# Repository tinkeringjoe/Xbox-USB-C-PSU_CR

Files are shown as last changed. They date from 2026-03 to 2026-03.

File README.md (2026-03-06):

This fork is for the following:

1) Reducing cost by using a cheap single IC that requires barely any supporting passives for USB-PD negotiating.
2) Updating power good signal to be an AND of the 4 power rails rather than a wired OR for power good.
3) Move components from back to front to simplify manufacturing.
4) Change from solder pads to through holes for power cabling; add enough holes for all XBOX revisions cabling.

Goals 1-4 completed. Additionally changed the following.
Inductor/output capacitors for all power rails have been updated per datasheet equations to minimize ripple.
Cost reduced components (BOM will remain hidden until testing is completed.)

This board supports the following power on the rails with an expected ripple of around 1%
5V - 15A
12V - 1.5A
3.3V - 5A
3.3VSB - 700mA

5 turn-key boards have been ordered to test. The following testing is to occur before even touching an XBOX.

1.) Power supply ripple is to be measured under the following conditions (1%, 25%, 50%, 100% of peak load). Should not exeed 5%.
2.) Load removal testing; 100% to 0% load. Should not exceed 10% of voltage rail.

Once these requirements have been satisfied real-hardware testing can occur.

# Xbox-USB-C-PSU
The first ever USB C PSU for the original Xbox

# NOTE:
This board currently supports all 3 Xbox motherboard revisions, but requires a different BOM for 009 and 012 than 121.
If you don't know what revision your Xbox is, you can find out with this guide: [https://www.herringhardware.com/xboxrevisions](https://www.herringhardware.com/XboxRevisions.html)

# REPO STRUCTURE:
All source files for the PCB are contained within the respective folder for each of the 3 official Xbox PCB revions,
-121 to start with, and -009 and -012 will be added soon.
Production files to manufacture the PCBs are located in [Releases](https://github.com/Redherring32/Xbox-USB-C-PSU/releases)

# PCB SPECS:
* 4 layers
* 151.739x39.78mm
* 1oz copper (all layers), heat issues may result from skimping on this
* filled vias (VIPPO) for assembly reasons due to via in pad

kicad_rvZLV58yR5

## LICENSE:
Licensed under
the TAPR Open hardware license (www.tapr.org/OHL)

©Redherring32 2025

## DISCLAIMER:
I offer this with no warranty, express or implied, and I am NOT responsible for anything that may happen as a result of misuse of this PCB.
You have been warned.

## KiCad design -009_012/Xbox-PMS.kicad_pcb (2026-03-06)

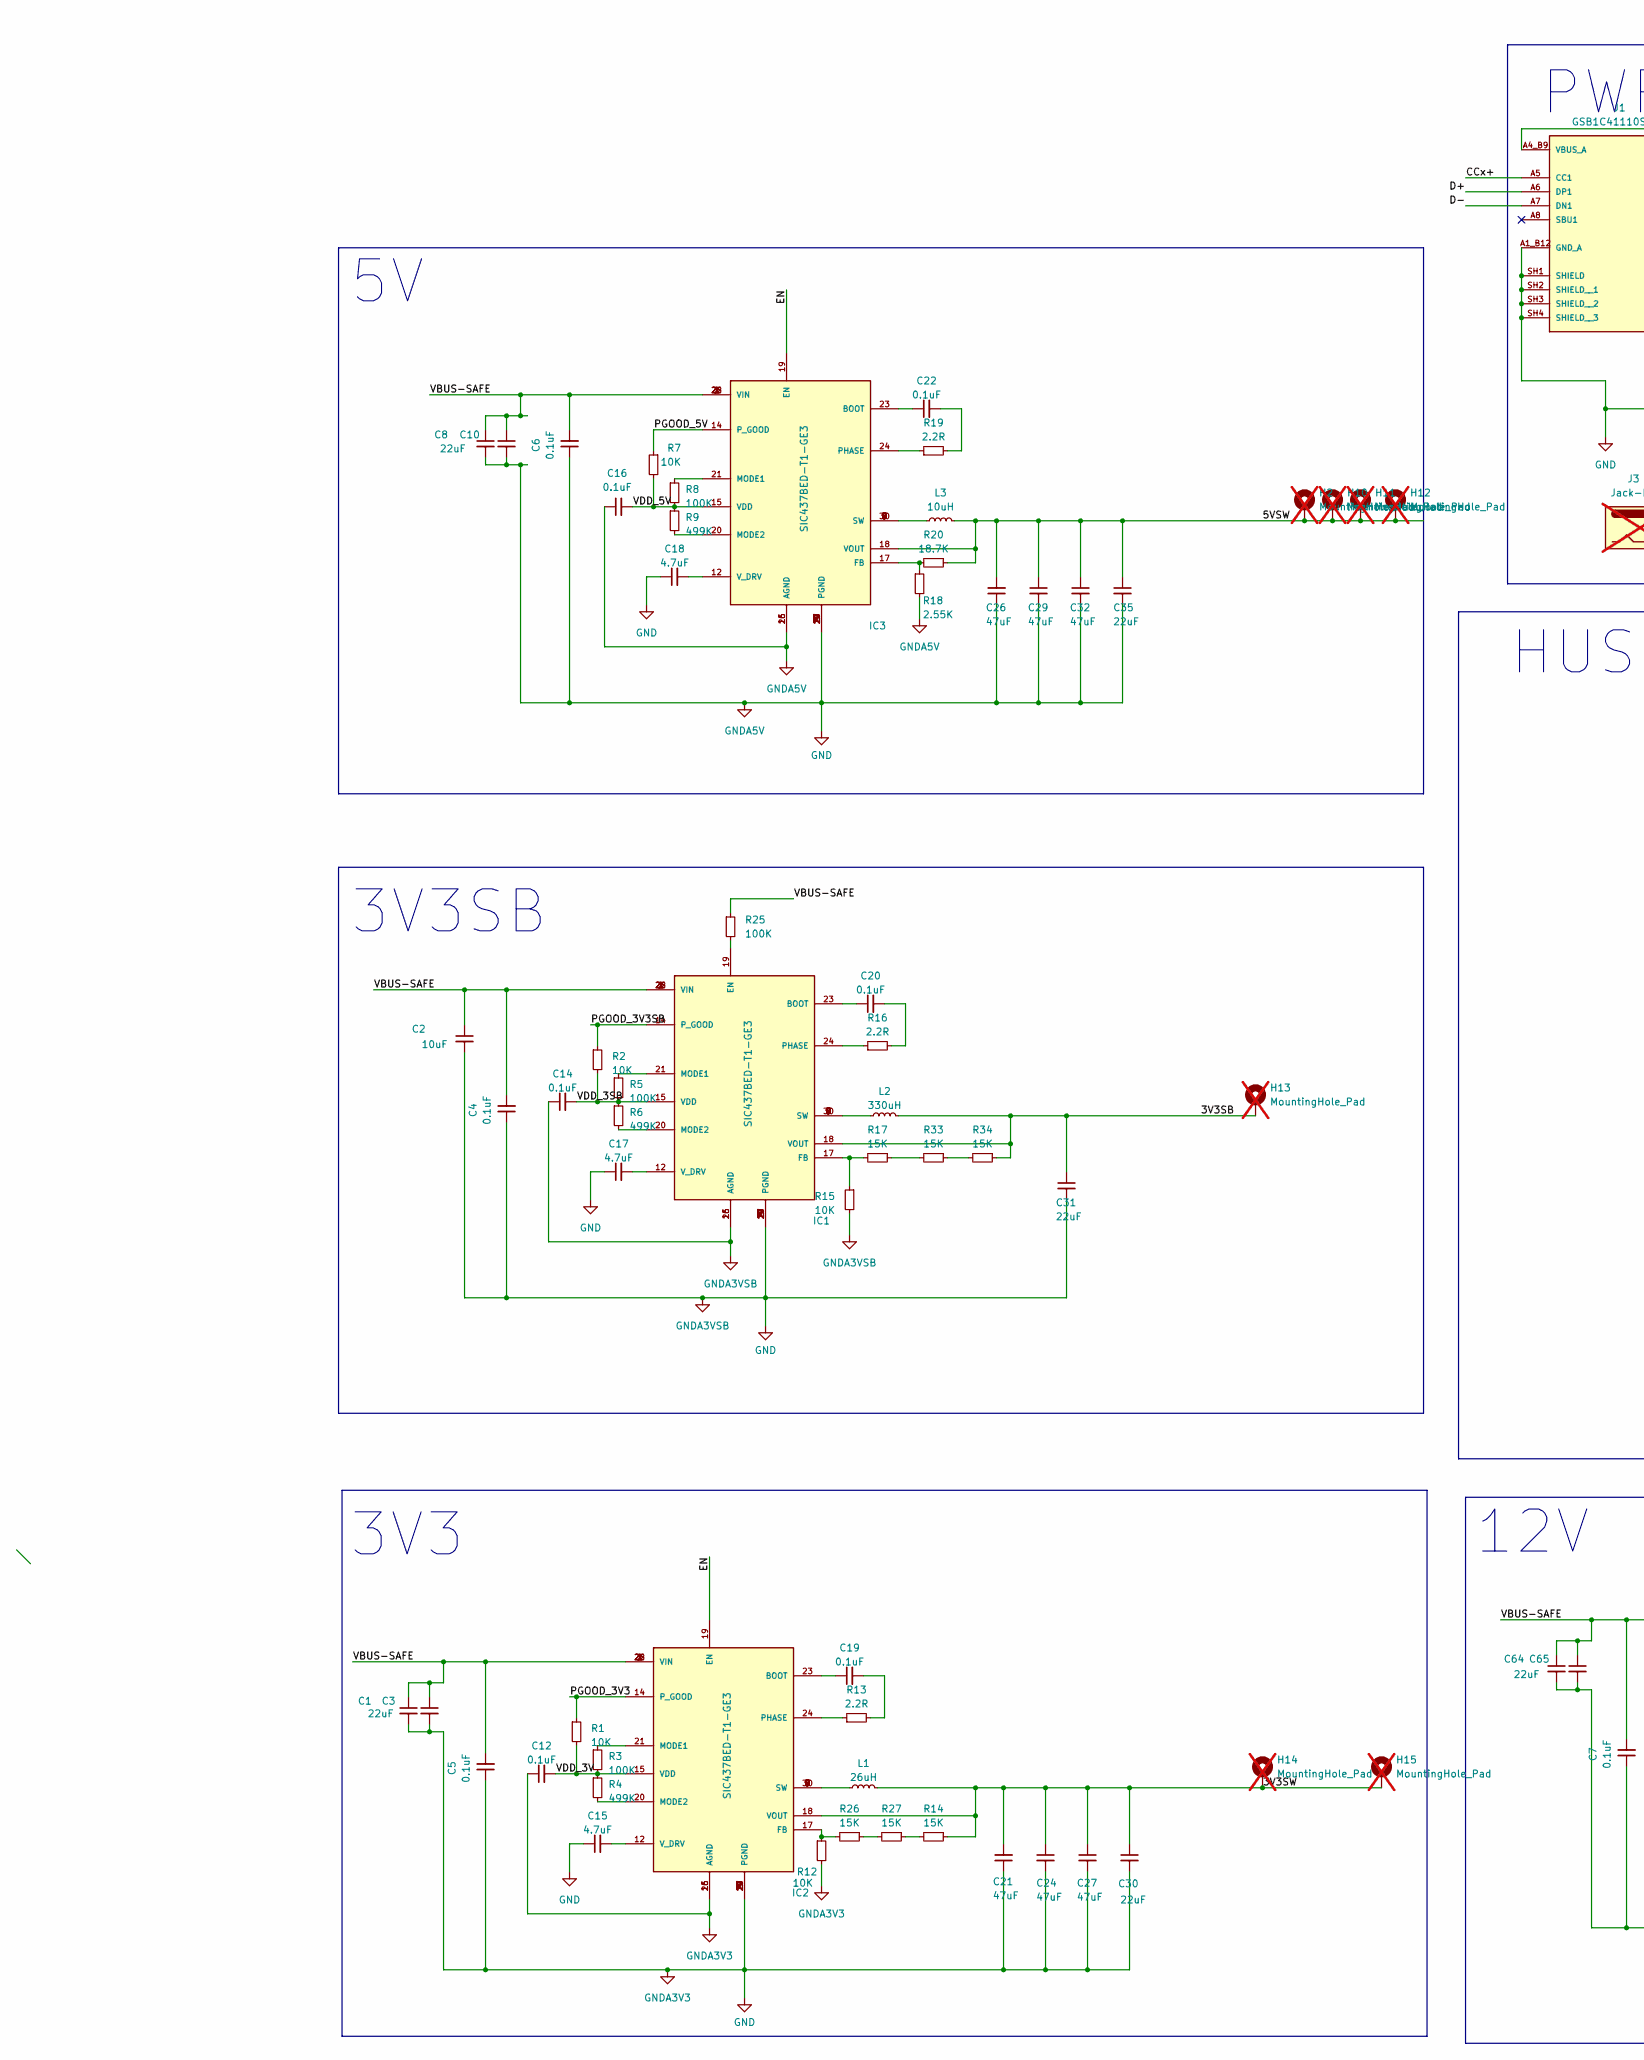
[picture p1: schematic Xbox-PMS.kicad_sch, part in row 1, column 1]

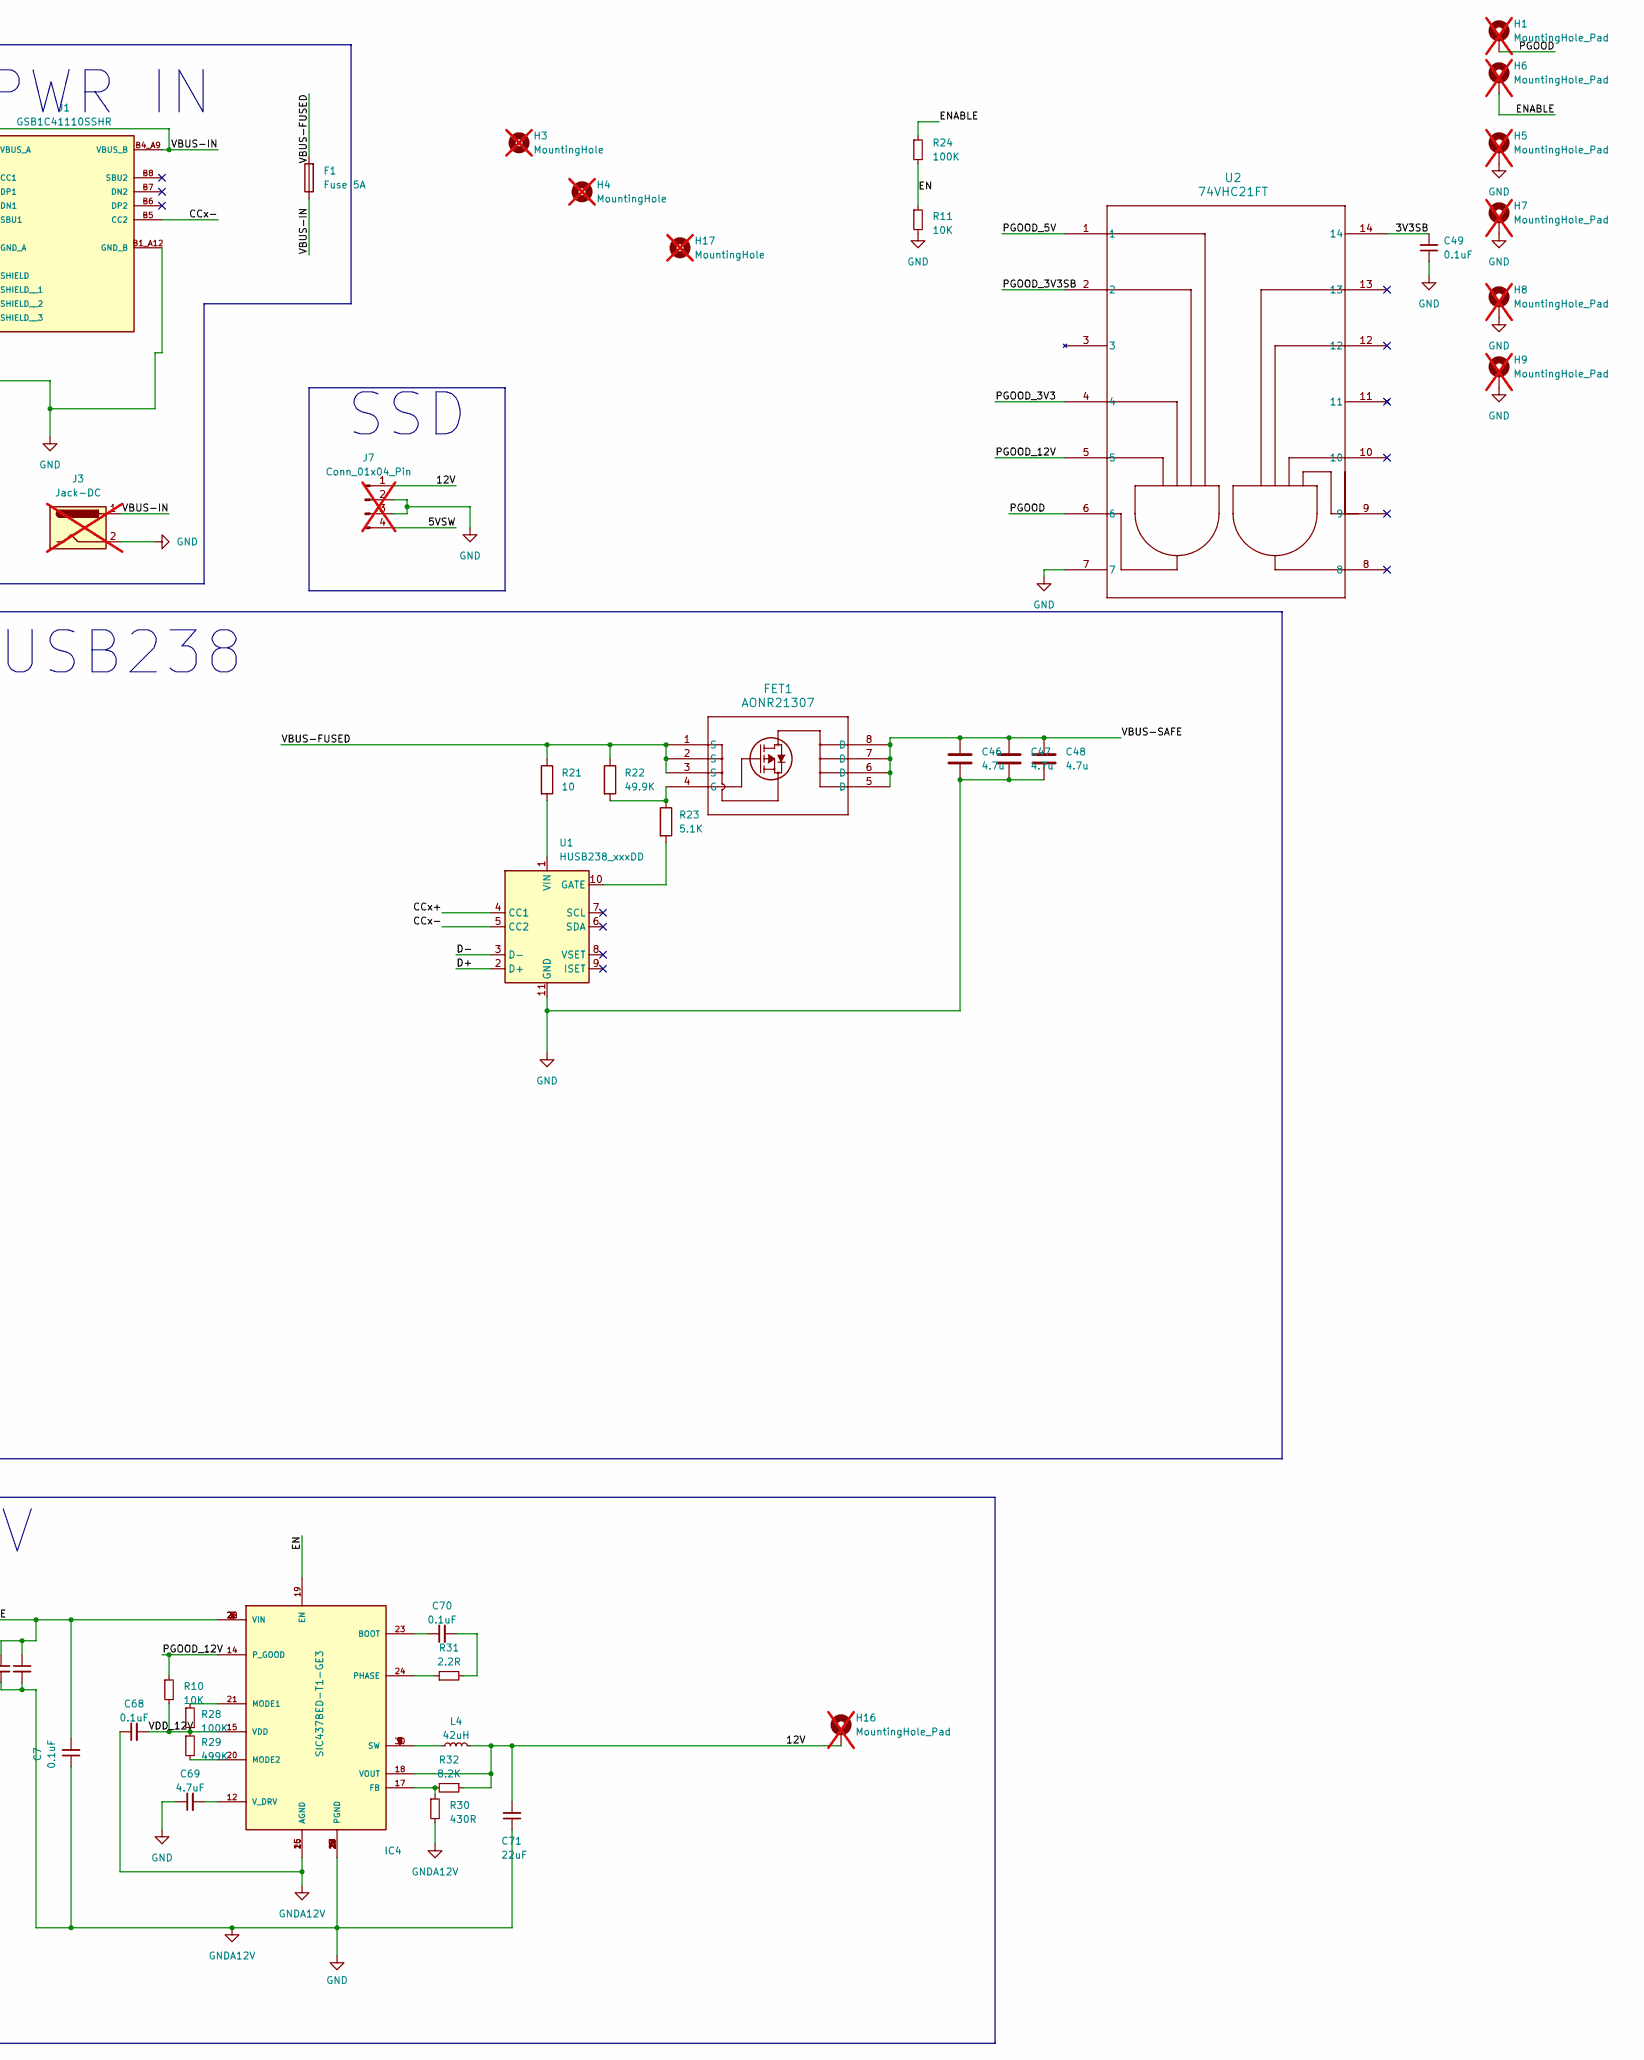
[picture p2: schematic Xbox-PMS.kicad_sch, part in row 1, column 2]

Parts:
C1, C3, C8, C10, C64, C65: 22uF; C_1210_3225Metric
C2: 10uF; C_1210_3225Metric
C4, C5, C6, C7, C12, C14, C16, C19, C20, C22, C49, C68, C70: 0.1uF; C_0402_1005Metric
C15, C17, C18, C69: 4.7uF; C_0603_1608Metric
C21, C24, C26, C27, C29, C32: 47uF; C_1210_3225Metric
C30, C31, C35: 22uF; C_0603_1608Metric
C46, C47, C48: 4.7u; C_1210_3225Metric
C71: 22uF; R_0805_2012Metric
F1: Fuse 5A; Fuse_2512_6332Metric
FET1: AONR21307; DFN8_3x3_EP_AOS
H1, H2, H5, H6, H7, H8, H9, H10, H11, H12, H13, H14, H15, H16: MountingHole_Pad; TestPoint_THTPad_2.5x2.5mm_Drill1.2mm; not fitted
H3, H4, H17: MountingHole; MountingHole_2.2mm_M2; not fitted
IC1, IC2, IC3, IC4: SIC437BED-T1-GE3; SIC437BEDT1GE3
J1: GSB1C41110SSHR; AMPHENOL_GSB1C41110SSHR; PARTREV AX1
J3: Jack-DC; BarrelJack_CUI_PJ-063AH_Horizontal; not fitted
J7: Conn_01x04_Pin; FDD Connector; not fitted
L1: 26uH; fch1350-270M
L2: 330uH; IND_SRN8040TA-331M
L3: 10uH; MDA1870-100M
L4: 42uH; IND_ETQ-P4M470KFM_PAN
R1, R2, R7, R10, R11, R12, R15: 10K; R_0402_1005Metric
R3, R5, R8, R24, R25, R28: 100K; R_0402_1005Metric
R4, R6, R9, R29: 499K; R_0402_1005Metric
R13, R16, R19, R31: 2.2R; R_0402_1005Metric
R14, R17, R26, R27, R33, R34: 15K; R_0402_1005Metric
R18: 2.55K; R_0402_1005Metric
R20: 18.7K; R_0402_1005Metric
R21: 10; R_0402_1005Metric
R22: 49.9K; R_0402_1005Metric
R23: 5.1K; R_0402_1005Metric
R30: 430R; R_0402_1005Metric
R32: 8.2K; R_0402_1005Metric
U1: HUSB238_xxxDD; WDFN-10-1EP_3x3mm_P0.5mm_EP1.8x2.5mm
U2: 74VHC21FT; TSSOP14B_TOS

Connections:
/3V3SB: C31.1, C49.2, H13.1, IC1.18 (VOUT), L2.2, R34.1, U2.14
/3V3SW: C21.2, C24.1, C27.1, C30.1, H14.1, H15.1, IC2.18 (VOUT), L1.2, R14.1
/5VSW: C26.2, C29.1, C32.1, C35.1, H2.1, H10.1, H11.1, H12.1, IC3.18 (VOUT), J7.4, L3.2, R20.1
/12V: C71.2, H16.1, IC4.18 (VOUT), J7.1, L4.2, R32.1
/CCx+: J1.A5 (CC1), U1.4 (CC1)
/CCx-: J1.B5 (CC2), U1.5 (CC2)
/D+: J1.A6 (DP1), U1.2 (D+)
/D-: J1.A7 (DN1), U1.3 (D-)
/EN: IC2.19 (EN), IC3.19 (EN), IC4.19 (EN), R11.1, R24.2
/ENABLE: H6.1, R24.1
/PGOOD: H1.1, U2.6
/PGOOD_3V3: IC2.14 (P_GOOD), R1.1, U2.4
/PGOOD_3V3SB: IC1.14 (P_GOOD), R2.1, U2.2
/PGOOD_5V: IC3.14 (P_GOOD), R7.1, U2.1
/PGOOD_12V: IC4.14 (P_GOOD), R10.1, U2.5
/VBUS-FUSED: F1.2, FET1.1 (S), FET1.2 (S), FET1.3 (S), R21.1, R22.1
/VBUS-IN: F1.1, J1.A4_B9 (VBUS_A), J1.B4_A9 (VBUS_B), J3.1
/VBUS-SAFE: C1.1, C2.1, C3.1, C4.2, C5.2, C6.2, C7.2, C8.1, C10.1, C46.1, C47.1, C48.1, C64.1, C65.1, FET1.5 (D), FET1.6 (D), FET1.7 (D), FET1.8 (D), IC1.1 (VIN), IC1.2 (VIN), IC1.22 (VIN), IC1.26 (VIN), IC2.1 (VIN), IC2.2 (VIN), IC2.22 (VIN), IC2.26 (VIN), IC3.1 (VIN), IC3.2 (VIN), IC3.22 (VIN), IC3.26 (VIN), IC4.1 (VIN), IC4.2 (VIN), IC4.22 (VIN), IC4.26 (VIN), R25.1
/VDD_3SB: C14.2, IC1.15 (VDD), R2.2, R5.2, R6.1
/VDD_3V: C12.2, IC2.15 (VDD), R1.2, R3.2, R4.1
/VDD_5V: C16.2, IC3.15 (VDD), R7.2, R8.2, R9.1
/VDD_12V: C68.2, IC4.15 (VDD), R10.2, R28.2, R29.1
GND: C1.2, C2.2, C3.2, C4.1, C5.1, C6.1, C7.1, C8.2, C10.2, C12.1, C14.1, C15.1, C16.1, C17.1, C18.1, C21.1, C24.2, C26.1, C27.2, C29.2, C30.2, C31.2, C32.2, C35.2, C46.2, C47.2, C48.2, C49.1, C64.2, C65.2, C68.1, C69.1, C71.1, H5.1, H7.1, H8.1, H9.1, IC1.3 (PGND), IC1.4 (PGND), IC1.13 (PGND), IC1.16 (AGND), IC1.25 (AGND), IC1.27 (PGND), IC1.29 (PGND), IC2.3 (PGND), IC2.4 (PGND), IC2.13 (PGND), IC2.16 (AGND), IC2.25 (AGND), IC2.27 (PGND), IC2.29 (PGND), IC3.3 (PGND), IC3.4 (PGND), IC3.13 (PGND), IC3.16 (AGND), IC3.25 (AGND), IC3.27 (PGND), IC3.29 (PGND), IC4.3 (PGND), IC4.4 (PGND), IC4.13 (PGND), IC4.16 (AGND), IC4.25 (AGND), IC4.27 (PGND), IC4.29 (PGND), J1.A1_B12 (GND_A), J1.B1_A12 (GND_B), J1.SH1 (SHIELD), J1.SH2 (SHIELD__1), J1.SH3 (SHIELD__2), J1.SH4 (SHIELD__3), J3.2, J7.2, J7.3, R11.2, R12.2, R15.2, R18.2, R30.2, U1.11 (GND), U2.7
unnamed: C19.2, R13.2
unnamed: C20.2, R16.2
unnamed: C22.2, R19.2
unnamed: C70.2, R31.2
unnamed: FET1.4 (G), R22.2, R23.1
unnamed: C20.1, IC1.23 (BOOT)
unnamed: IC1.19 (EN), R25.2
unnamed: IC1.17 (FB), R15.1, R17.2
unnamed: IC1.21 (MODE1), R5.1
unnamed: IC1.20 (MODE2), R6.2
unnamed: IC1.24 (PHASE), R16.1
unnamed: IC1.5 (SW), IC1.6 (SW), IC1.7 (SW), IC1.8 (SW), IC1.9 (SW), IC1.30 (SW), L2.1
unnamed: C17.2, IC1.12 (V_DRV)
unnamed: C19.1, IC2.23 (BOOT)
unnamed: IC2.17 (FB), R12.1, R26.2
unnamed: IC2.21 (MODE1), R3.1
unnamed: IC2.20 (MODE2), R4.2
unnamed: IC2.24 (PHASE), R13.1
unnamed: IC2.5 (SW), IC2.6 (SW), IC2.7 (SW), IC2.8 (SW), IC2.9 (SW), IC2.30 (SW), L1.1
unnamed: C15.2, IC2.12 (V_DRV)
unnamed: C22.1, IC3.23 (BOOT)
unnamed: IC3.17 (FB), R18.1, R20.2
unnamed: IC3.21 (MODE1), R8.1
unnamed: IC3.20 (MODE2), R9.2
unnamed: IC3.24 (PHASE), R19.1
unnamed: IC3.5 (SW), IC3.6 (SW), IC3.7 (SW), IC3.8 (SW), IC3.9 (SW), IC3.30 (SW), L3.1
unnamed: C18.2, IC3.12 (V_DRV)
unnamed: C70.1, IC4.23 (BOOT)
unnamed: IC4.17 (FB), R30.1, R32.2
unnamed: IC4.21 (MODE1), R28.1
unnamed: IC4.20 (MODE2), R29.2
unnamed: IC4.24 (PHASE), R31.1
unnamed: IC4.5 (SW), IC4.6 (SW), IC4.7 (SW), IC4.8 (SW), IC4.9 (SW), IC4.30 (SW), L4.1
unnamed: C69.2, IC4.12 (V_DRV)
unnamed: R14.2, R27.1
unnamed: R17.1, R33.2
unnamed: R26.1, R27.2
unnamed: R33.1, R34.2
unnamed: R23.2, U1.10 (GATE)
unnamed: R21.2, U1.1 (VIN)

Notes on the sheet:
PWR IN
3V3
12V
3V3SB
SSD
HUSB238

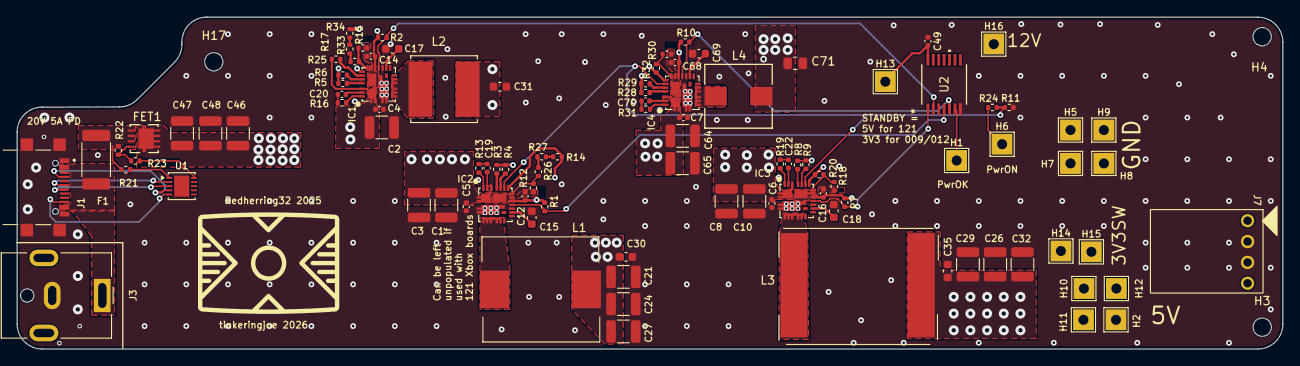
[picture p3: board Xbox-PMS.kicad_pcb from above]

Board: 4 copper layers, 151.7 x 39.8 mm, 103 parts (0 on the bottom side), 63 nets.

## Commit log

2026-03-06 Initial Changes
    Updates for the following:
    1.) Updated all inductor and capacitance values per equations in datasheet. Should minimize power supply ripple and minimize part cost.
    2.) Added AND gate for power good output
    3.) Rerouted board for simplicity and noise isolation.
    [Xbox-PMS.kicad_pcb, Xbox-PMS.kicad_sch]
2026-03-06 Revise README with goals and testing details
    Updated README with completed goals and testing requirements for power supply.
